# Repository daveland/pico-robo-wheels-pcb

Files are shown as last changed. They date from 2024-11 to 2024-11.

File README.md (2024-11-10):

PCB in Kicad7 For pico-robo-wheels
RP 2040/ or Rp2350 compatible
This board will connecto to Either 100amp or 20 amp H-Bridge drivers On Ebay/aliexpress
It allows 2 motorized wheels in a differtial drive turning system
Each Wheel has a quadrature encoder to sense velocity and position
The cables to the encoders support 5V to the encoder , shifted to 3.3V via resistor dividers
OLD 0.9 inch display lets configuration , debug and control be performed
Rotry input encoder with switch for menu interaction
Estop input and Switch to stop all motion immediatly

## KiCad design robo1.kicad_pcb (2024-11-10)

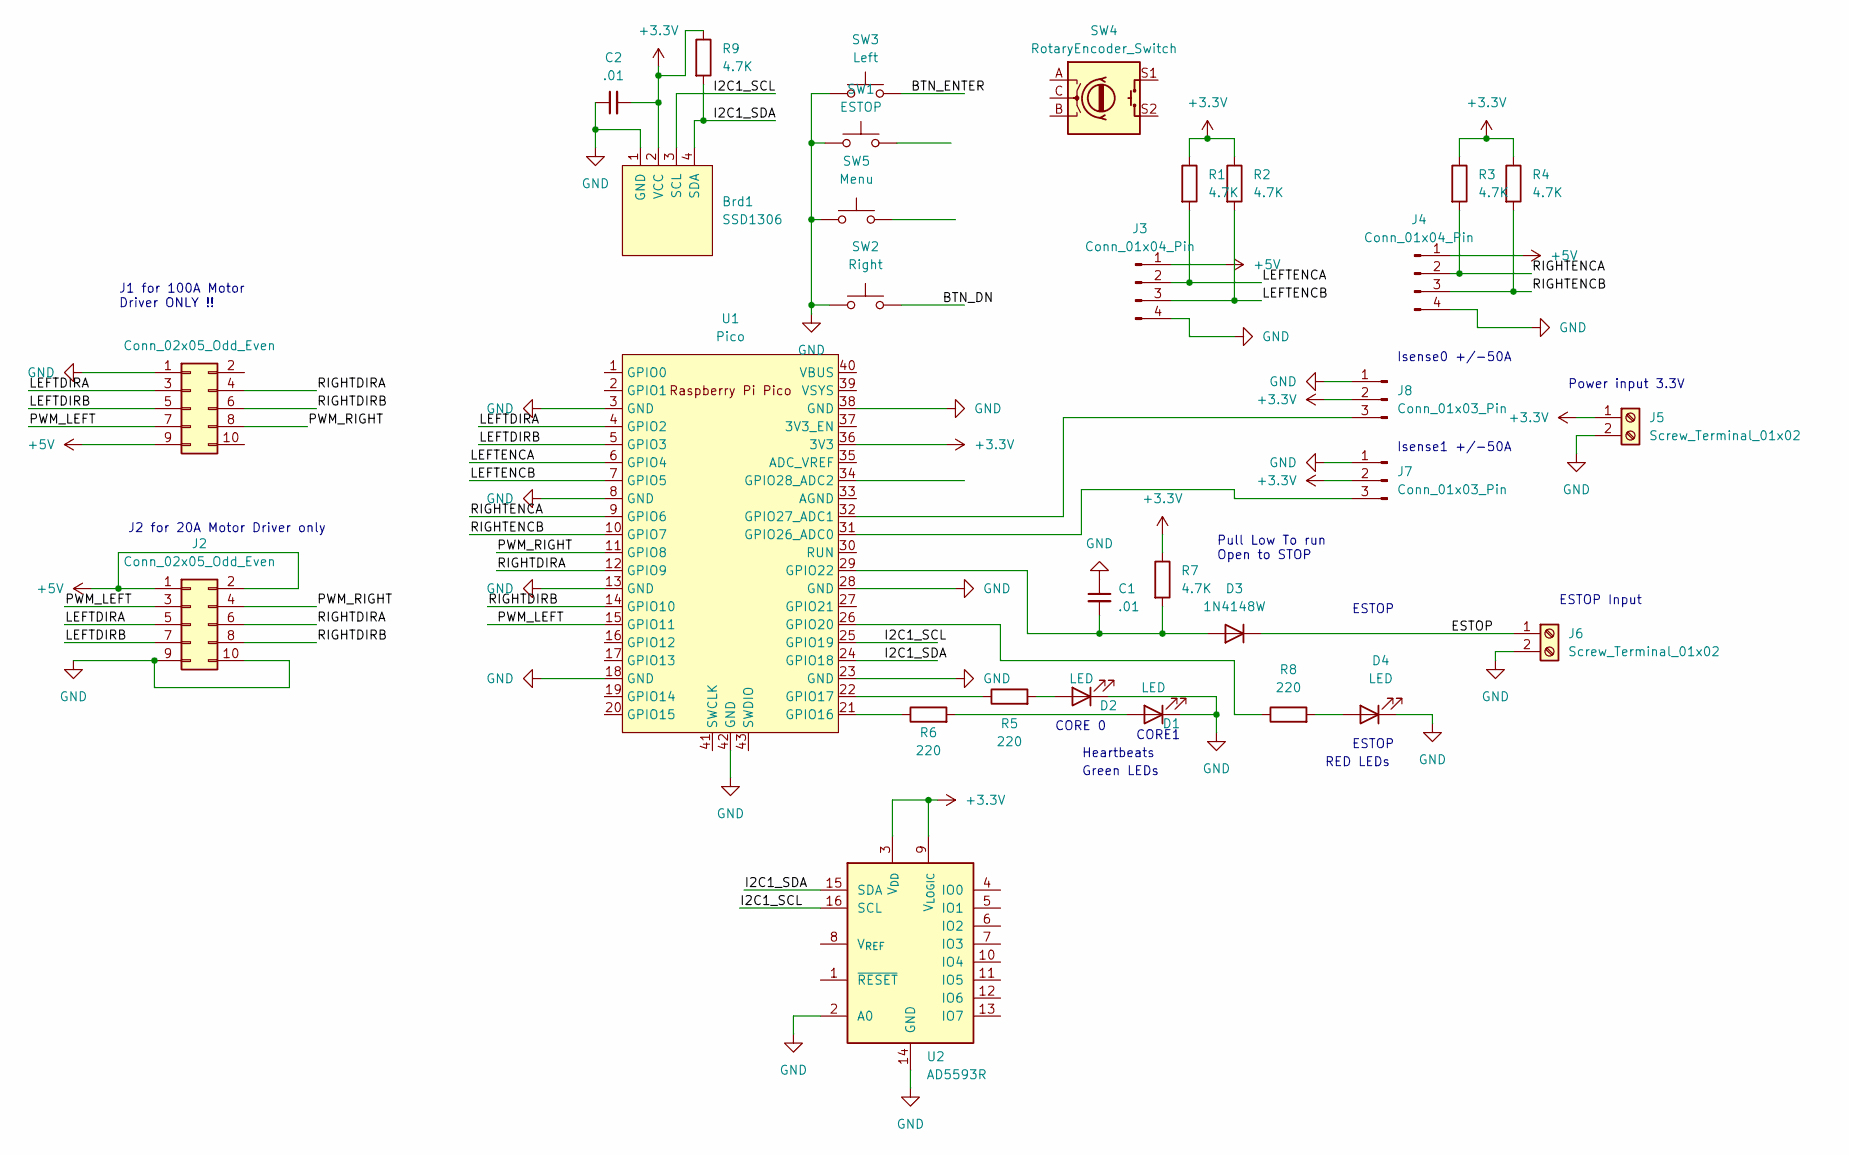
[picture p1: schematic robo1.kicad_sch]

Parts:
Brd1: SSD1306; 128x64OLED
C1, C2: .01; C_0603_1608Metric_Pad1.08x0.95mm_HandSolder
D1, D2, D4: LED; LED_1206_3216Metric_Pad1.42x1.75mm_HandSolder
D3: 1N4148W; D_SOD-123
J1, J2: Conn_02x05_Odd_Even; PinHeader_2x05_P2.54mm_Vertical
J3, J4: Conn_01x04_Pin; PinHeader_1x04_P2.54mm_Vertical
J5, J6: Screw_Terminal_01x02; TerminalBlock_bornier-2_P5.08mm
J7, J8: Conn_01x03_Pin; PinHeader_1x03_P2.54mm_Vertical
R1, R2, R3, R4, R7, R9: 4.7K; R_0201_0603Metric_Pad0.64x0.40mm_HandSolder
R5, R6, R8: 220; R_0201_0603Metric_Pad0.64x0.40mm_HandSolder
SW1: ESTOP; SW_PUSH_6mm
SW2: Right; SW_PUSH_6mm
SW3: Left; SW_PUSH_6mm
SW4: RotaryEncoder_Switch; RotaryEncoder_Alps_EC11E-Switch_Vertical_H20mm_CircularMoun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
SW5: Menu; SW_PUSH_6mm
U1: Pico; RPi_Pico_SMD_TH
U2: AD5593R; TSSOP-16_4.4x5mm_P0.65mm

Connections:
+3.3V: Brd1.2 (VCC), C2.2, J5.1, J7.2, J8.2, R1.1, R2.1, R3.1, R4.1, R7.1, R9.1, U1.36 (3V3), U2.3 (V_{DD}), U2.9 (V_{LOGIC})
+5V: J1.9, J2.1, J2.2, J3.1, J4.1
/BTN_DN: SW2.2
/BTN_ENTER: SW3.2
/ESTOP: D3.1 (K), J6.1
/I2C1_SCL: Brd1.3 (SCL), U1.25 (GPIO19), U2.16 (SCL)
/I2C1_SDA: Brd1.4 (SDA), R9.2, U1.24 (GPIO18), U2.15 (SDA)
/LEFTDIRA: J1.3, J2.5, U1.4 (GPIO2)
/LEFTDIRB: J1.5, J2.7, U1.5 (GPIO3)
/LEFTENCA: J3.2, R1.2, U1.6 (GPIO4)
/LEFTENCB: J3.3, R2.2, U1.7 (GPIO5)
/PWM_LEFT: J1.7, J2.3, U1.15 (GPIO11)
/PWM_RIGHT: J1.8, J2.4, U1.11 (GPIO8)
/RIGHTDIRA: J1.4, J2.6, U1.12 (GPIO9)
/RIGHTDIRB: J1.6, J2.8, U1.14 (GPIO10)
/RIGHTENCA: J4.2, R3.2, U1.9 (GPIO6)
/RIGHTENCB: J4.3, R4.2, U1.10 (GPIO7)
GND: Brd1.1 (GND), C1.1, C2.1, D1.1 (K), D2.1 (K), D4.1 (K), J1.1, J2.9, J2.10, J3.4, J4.4, J5.2, J6.2, J7.1, J8.1, SW1.1, SW2.1, SW3.1, SW5.1, U1.3 (GND), U1.8 (GND), U1.13 (GND), U1.18 (GND), U1.23 (GND), U1.28 (GND), U1.38 (GND), U1.42 (GND), U2.2 (A0), U2.14 (GND)
unnamed: D1.2 (A), R6.2
unnamed: D2.2 (A), R5.2
unnamed: C1.2, D3.2 (A), R7.2, U1.29 (GPIO22)
unnamed: D4.2 (A), R8.2
unnamed: J7.3, U1.31 (GPIO26_ADC0)
unnamed: J8.3, U1.32 (GPIO27_ADC1)
unnamed: R6.1, U1.21 (GPIO16)
unnamed: R5.1, U1.22 (GPIO17)
unnamed: R8.1, U1.26 (GPIO20)

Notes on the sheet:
ESTOP Input
J2 for 20A Motor Driver only
ESTOP
Isense0 +/-50A
Isense1 +/-50A
Heartbeats
Pull Low To run Open to STOP
Green LEDs
Power input 3.3V
J1 for 100A Motor Driver ONLY !!
CORE1
CORE 0
RED LEDs

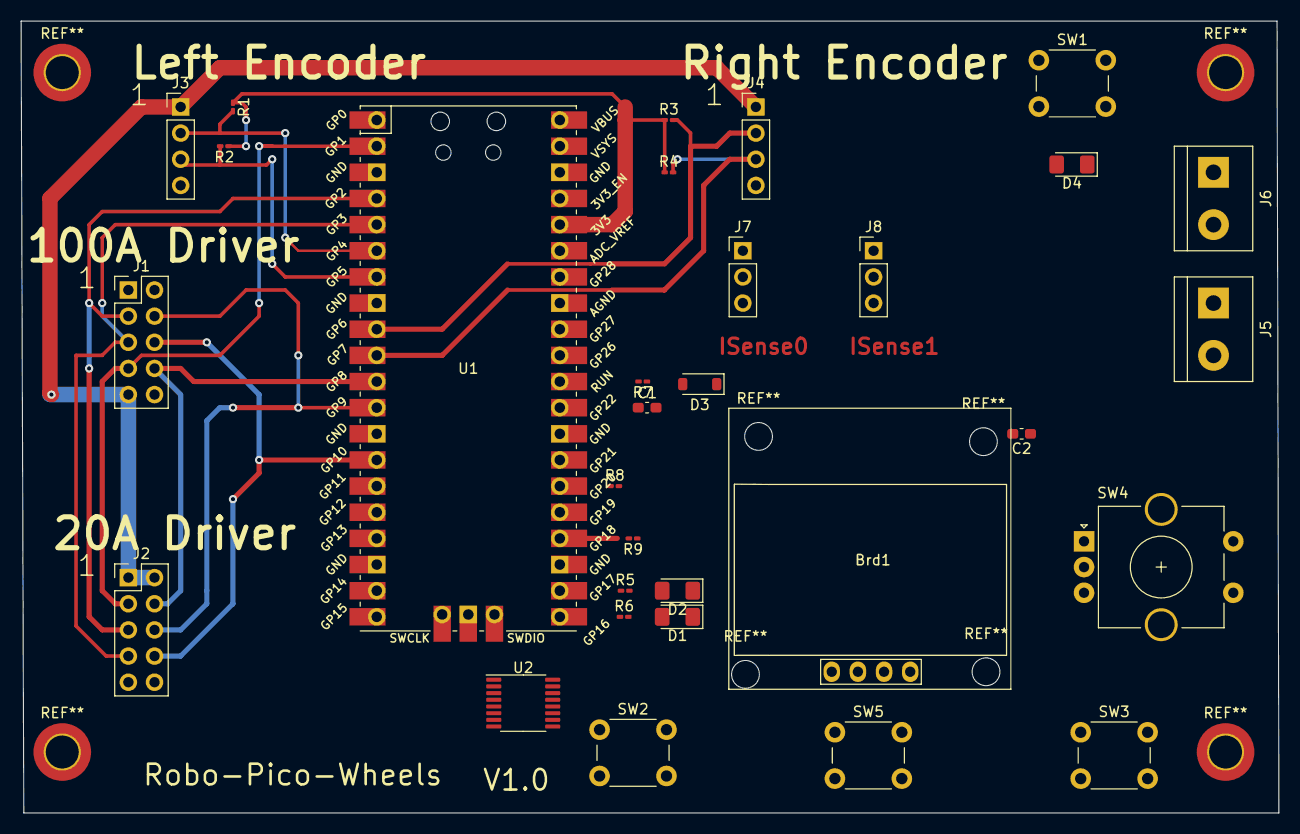
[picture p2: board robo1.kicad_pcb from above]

Board: 2 copper layers, 122.2 x 76.9 mm, 31 parts (0 on the bottom side), 25 nets.

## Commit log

2024-11-10 update to use ad5590 and pb encoder
    [robo1.kicad_pcb, robo1.kicad_sch]
2024-12-13 add 5593 gpio
    [robo1.kicad_sch]
